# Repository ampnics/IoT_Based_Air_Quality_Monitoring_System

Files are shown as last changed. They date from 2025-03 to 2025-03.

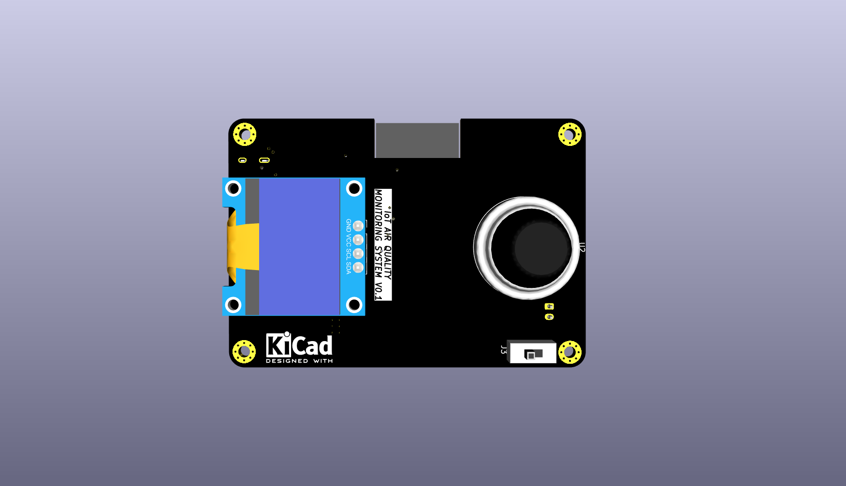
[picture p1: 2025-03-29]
Air_Quality_Monitor/Docs/Top_img.png

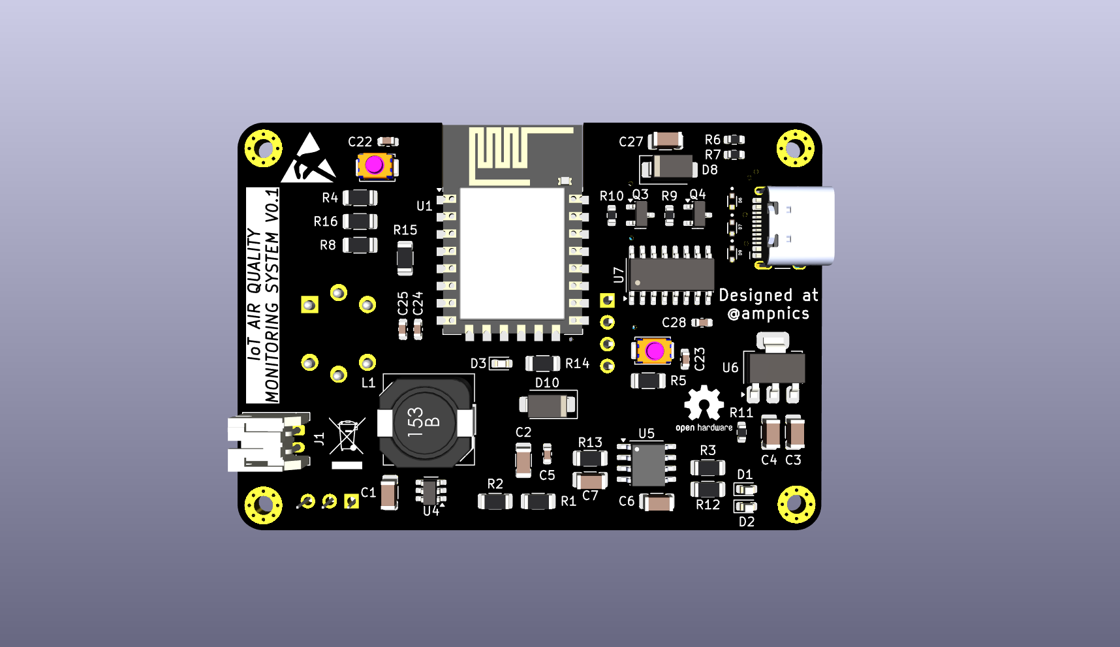
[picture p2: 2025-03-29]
Air_Quality_Monitor/Docs/Bottom_img.png

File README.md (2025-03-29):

# IoT_Based_Air_Quality_Monitoring_System
This project implements a real-time air quality monitoring system using IoT technology. It measures key environmental parameter like CO2 using sensors, then transmits data to a cloud platform via Wi-Fi.
A real-time air quality monitoring system that measures pollutants (CO2, NH3, NOx) and environmental parameters using IoT technology.

📋 Features
Real-time air quality monitoring using MQ135 gas sensor

OLED display for local readings

WiFi connectivity (ESP8266) for cloud data logging

Battery powered with TP4056 charging module

Compact design with CH340C USB-to-Serial interface

🛠 Hardware Components
ESP8266 - WiFi microcontroller

CH340C - USB-to-Serial converter

MT3608 - DC-DC boost converter (for 3.7V to 5V)

MQ135 - Air quality sensor (detects CO2, NH3, NOx)

AMS1117 - 3.3V voltage regulator

TP4056 - Lithium battery charging module

3.7V Li-ion Battery - Power source

0.96" OLED Display - I2C interface for local monitoring

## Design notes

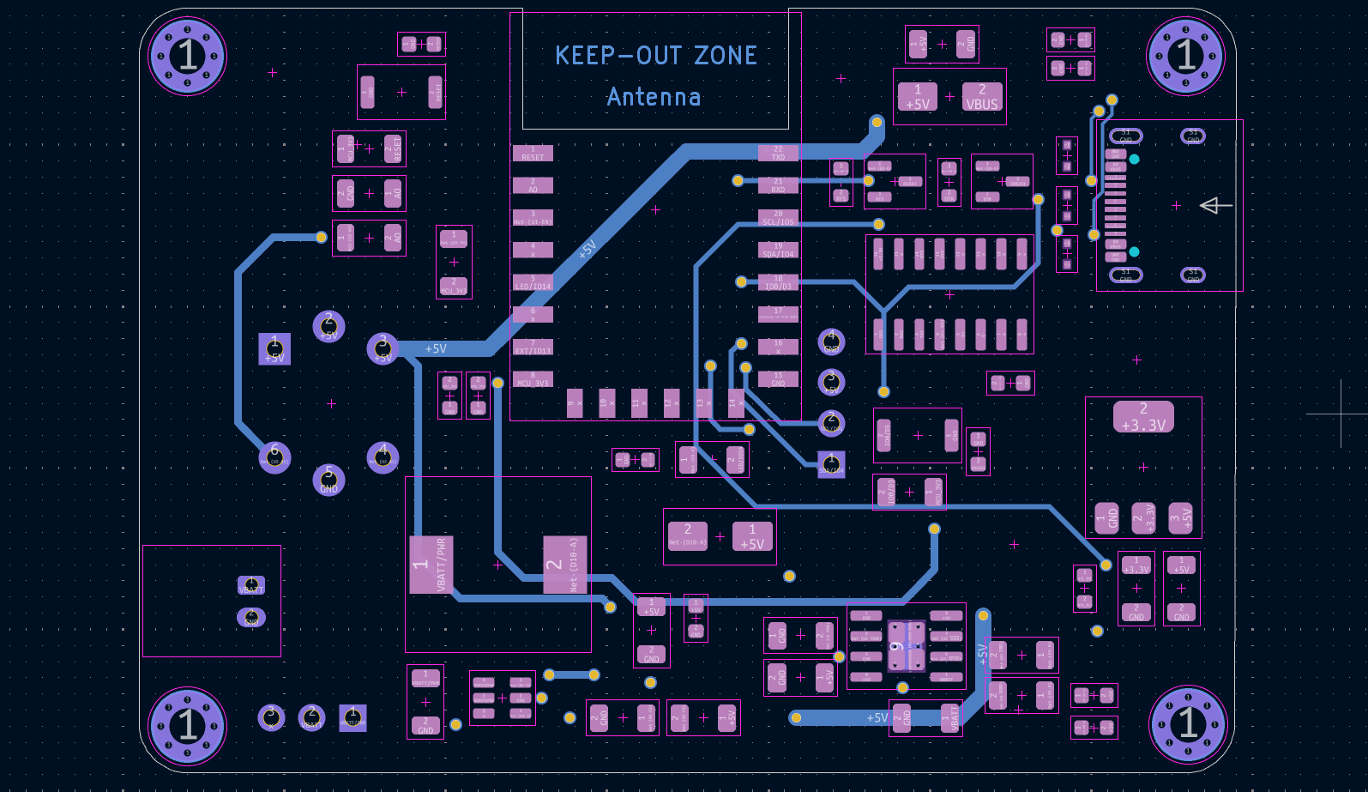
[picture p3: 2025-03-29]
Air_Quality_Monitor/Docs/B_Cu_Layout.png

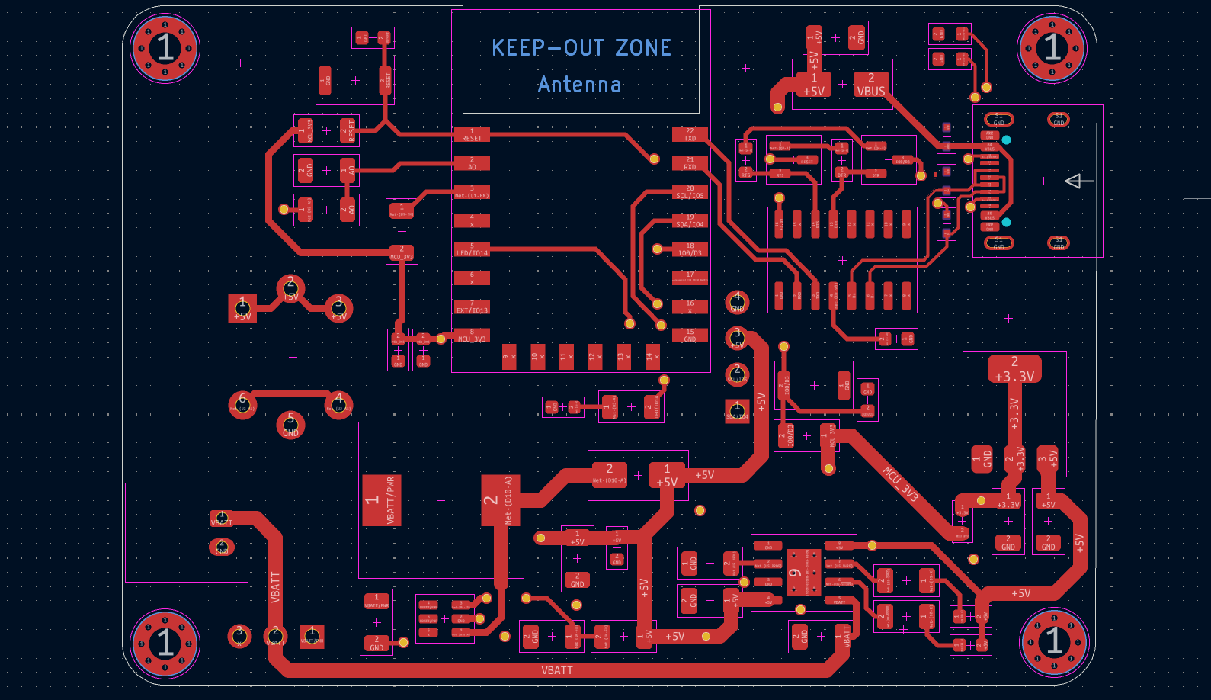
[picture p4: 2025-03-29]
Air_Quality_Monitor/Docs/F_Cu_Layout.png

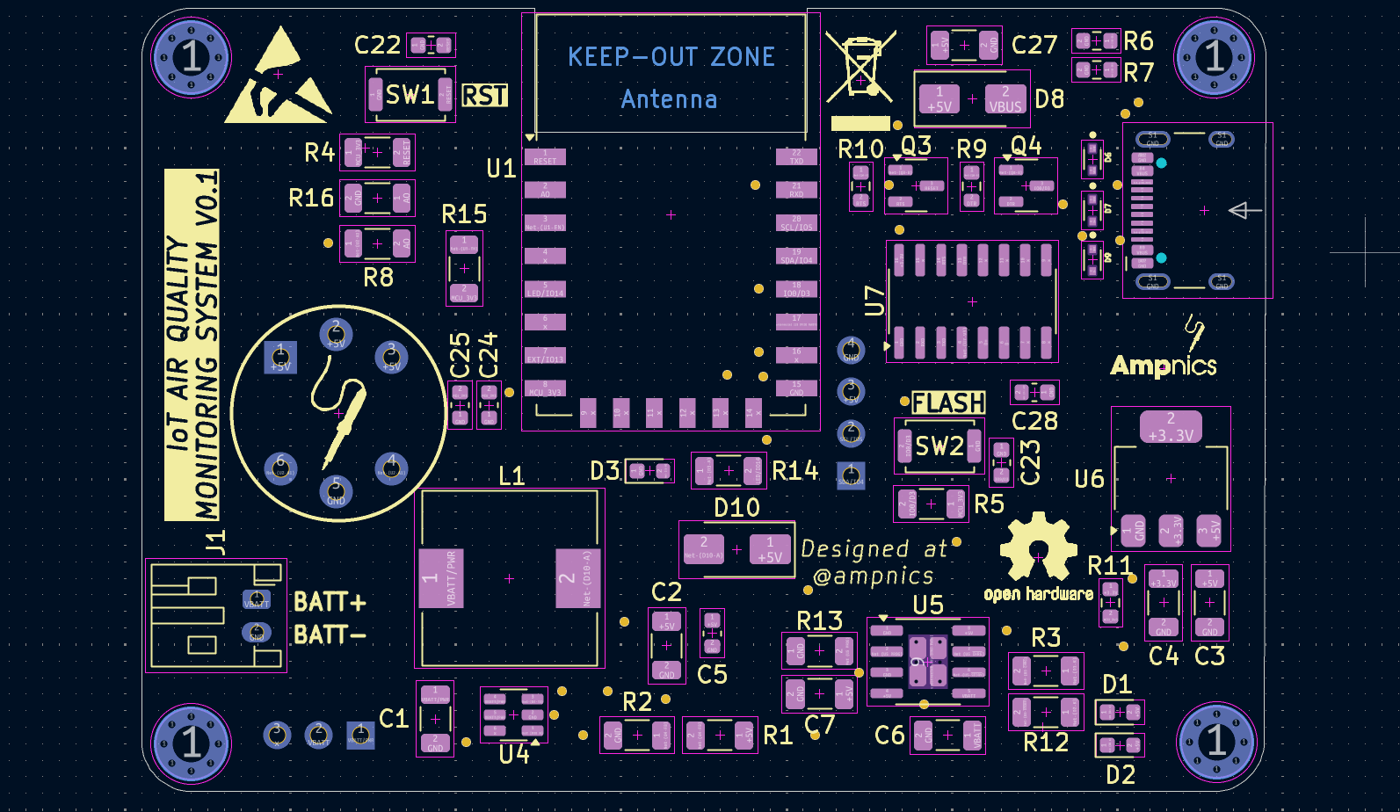
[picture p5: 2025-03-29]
Air_Quality_Monitor/Docs/F_Silkscreen.png

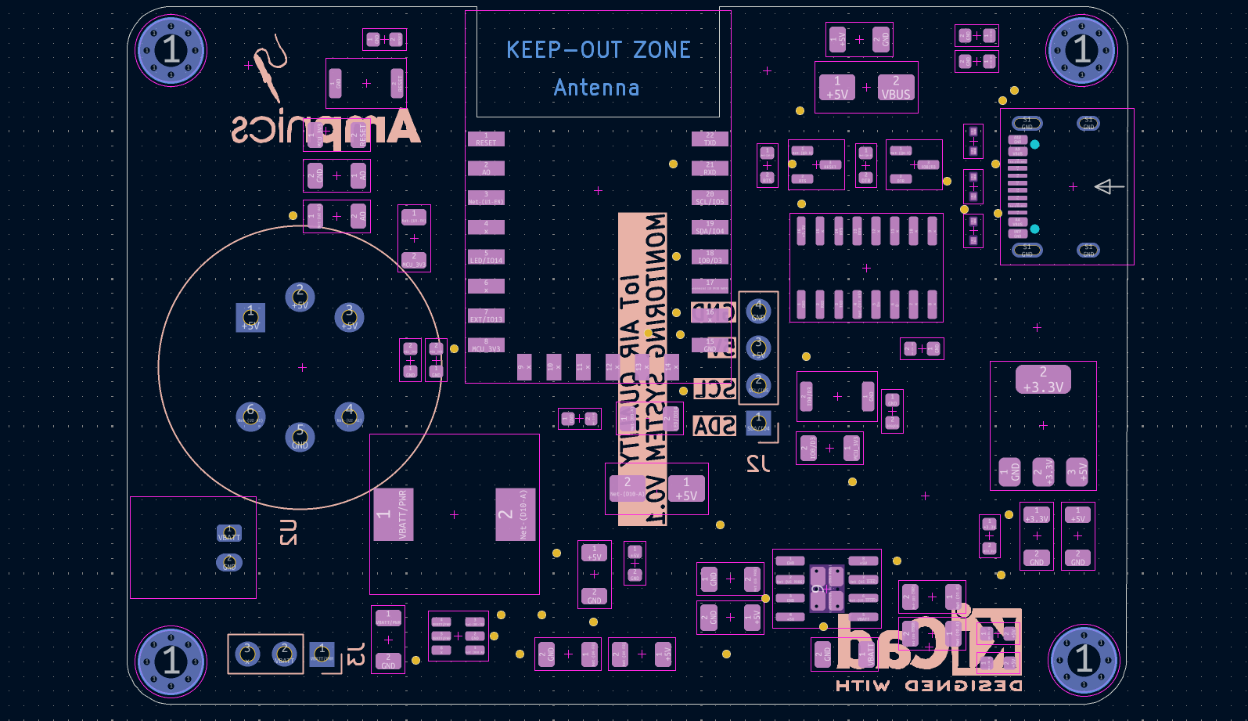
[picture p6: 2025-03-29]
Air_Quality_Monitor/Docs/B_Silkscreen.png

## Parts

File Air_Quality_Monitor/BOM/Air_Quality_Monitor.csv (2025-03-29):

Reference | Qty | Value | DNP | Exclude from BOM | Exclude from Board | Footprint | Datasheet
C1,C2 | 2 | 22uF |  |  |  | Capacitor_SMD:C_1206_3216Metric | ~
C3,C4,C6,C7 | 4 | 10uF |  |  |  | Capacitor_SMD:C_1206_3216Metric | ~
C5 | 1 | 0.1uF |  |  |  | Capacitor_SMD:C_0603_1608Metric | ~
C22,C23,C24,C25 | 4 | 0.1uf |  |  |  | Capacitor_SMD:C_0603_1608Metric | ~
C27 | 1 | 10uF/25V |  |  |  | Capacitor_SMD:C_1206_3216Metric | ~
C28 | 1 | 10nf |  |  |  | Capacitor_SMD:C_0603_1608Metric | ~
D1 | 1 | GREEN |  |  |  | LED_SMD:LED_0603_1608Metric | ~
D2,D3 | 2 | RED |  |  |  | LED_SMD:LED_0603_1608Metric | ~
D6,D7,D9 | 3 | LESD5D5.0CT1G |  |  |  | LESD5D5.0CT1G:TVS_LESD5D5.0CT1G
D8,D10 | 2 | SS34 |  |  |  | Diode_SMD:D_SMA | https://www.vishay.com/docs/88751/ss32.pdf
J1 | 1 | Conn_01x02_Pin |  |  |  | Connector_JST:JST_PH_S2B-PH-K_1x02_P2.00mm_Horizontal | ~
J2 | 1 | Conn_01x04_Pin |  |  |  | Connector_PinSocket_2.54mm:PinSocket_1x04_P2.54mm_Vertical | ~
J3 | 1 | Conn_01x03_Pin |  |  |  | Connector_PinHeader_2.54mm:PinHeader_1x03_P2.54mm_Vertical | ~
J23 | 1 | USB_C_Receptacle_USB2.0_16P |  |  |  | Connector_USB:USB_C_Receptacle_HCTL_HC-TYPE-C-16P-01A | https://www.usb.org/sites/default/files/documents/usb_type-c.zip
L1 | 1 | L |  |  |  | Inductor_SMD:L_10.4x10.4_H4.8 | ~
Q3,Q4 | 2 | SS8050 |  |  |  | Package_TO_SOT_SMD:SOT-23 | http://www.secosgmbh.com/datasheet/products/SSMPTransistor/SOT-23/SS8050.pdf
R1,R2 | 2 | R |  |  |  | Resistor_SMD:R_1206_3216Metric | ~
R3,R12,R16 | 3 | 1K |  |  |  | Resistor_SMD:R_1206_3216Metric | ~
R4,R5 | 2 | 10K |  |  |  | Resistor_SMD:R_1206_3216Metric | ~
R6,R7 | 2 | 5.1K |  |  |  | Resistor_SMD:R_0603_1608Metric | ~
R8 | 1 | 4.7K |  |  |  | Resistor_SMD:R_1206_3216Metric | ~
R9,R10 | 2 | 10k |  |  |  | Resistor_SMD:R_0603_1608Metric | ~
R11 | 1 | 0E |  |  |  | Resistor_SMD:R_0603_1608Metric | ~
R13 | 1 | 1K2 |  |  |  | Resistor_SMD:R_1206_3216Metric | ~
R14 | 1 | 220E |  |  |  | Resistor_SMD:R_1206_3216Metric | ~
R15 | 1 | 10k |  |  |  | Resistor_SMD:R_1206_3216Metric | ~
SW1,SW2 | 2 | SW_Push |  |  |  | Button_Switch_SMD:SW_Push_SPST_NO_Alps_SKRK | ~
U1 | 1 | ESP-12E |  |  |  | RF_Module:ESP-12E | http://wiki.ai-thinker.com/_media/esp8266/esp8266_series_modules_user_manual_v1.1.pdf
U2 | 1 | MQ-135 |  |  |  | Sensor:MQ-6 | https://www.winsen-sensor.com/d/files/semiconductor/mq-6.pdf
U4 | 1 | MT3608 |  |  |  | Package_TO_SOT_SMD:SOT-23-6 | https://www.olimex.com/Products/Breadboarding/BB-PWR-3608/resources/MT3608.pdf
U5 | 1 | TP4056-42-ESOP8 |  |  |  | Package_SO:SOIC-8-1EP_3.9x4.9mm_P1.27mm_EP2.41x3.3mm_ThermalVias | https://www.lcsc.com/datasheet/lcsc_datasheet_2410121619_TOPPOWER-Nanjing-Extension-Microelectronics-TP4056-42-ESOP8_C16581.pdf
U6 | 1 | AMS1117-3.3 |  |  |  | Package_TO_SOT_SMD:SOT-223-3_TabPin2 | http://www.advanced-monolithic.com/pdf/ds1117.pdf
U7 | 1 | CH340C |  |  |  | Package_SO:SOIC-16_3.9x9.9mm_P1.27mm | https://datasheet.lcsc.com/szlcsc/Jiangsu-Qin-Heng-CH340C_C84681.pdf

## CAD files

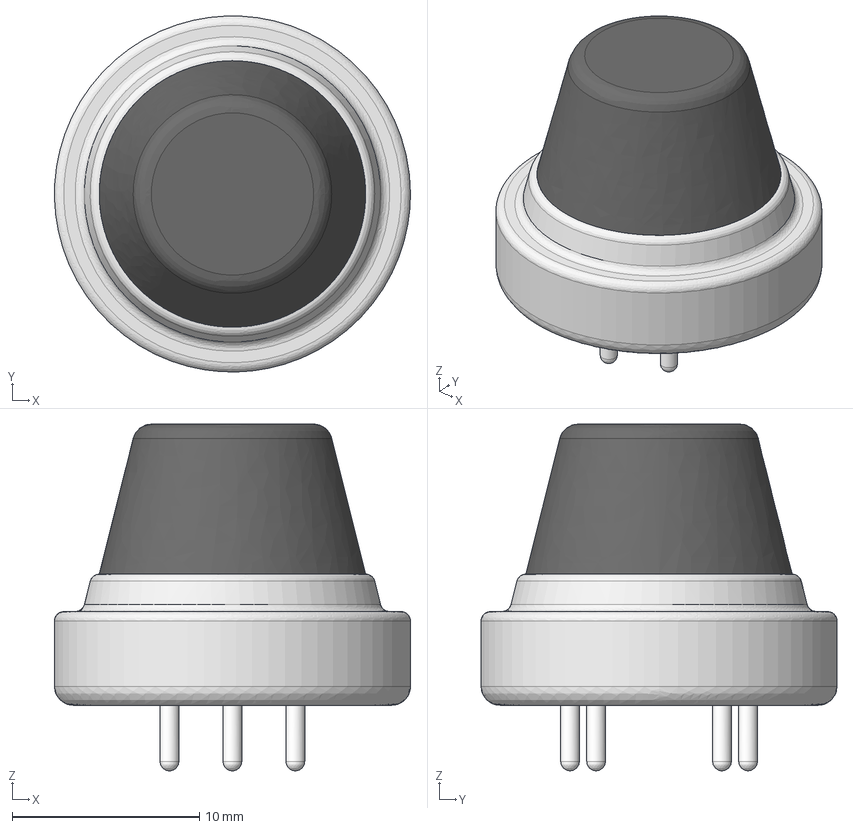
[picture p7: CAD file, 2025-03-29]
Air_Quality_Monitor/External 3d model/mq-8-gas-sensor-1.snapshot.1/MQ-8 gas sensor.stp
19.0 x 19.0 x 18.5 mm

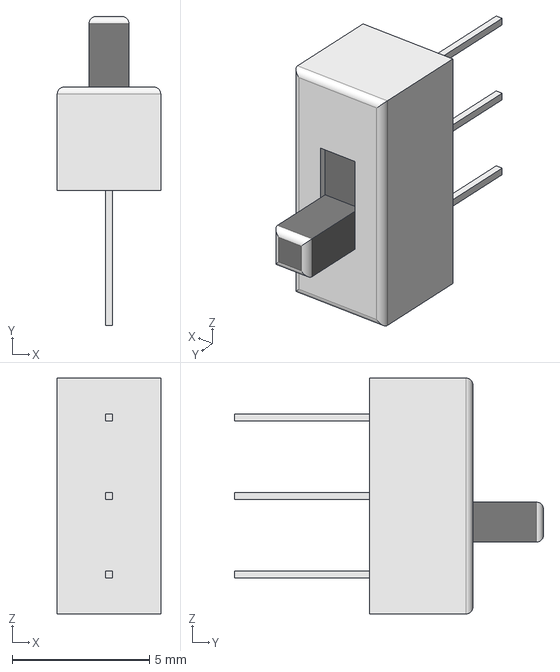
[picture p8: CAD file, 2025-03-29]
Air_Quality_Monitor/External 3d model/Vertical slide switch SS-12D00G3 High Knob 3mm SPDT v2.step
3.77 x 11.2 x 8.59 mm

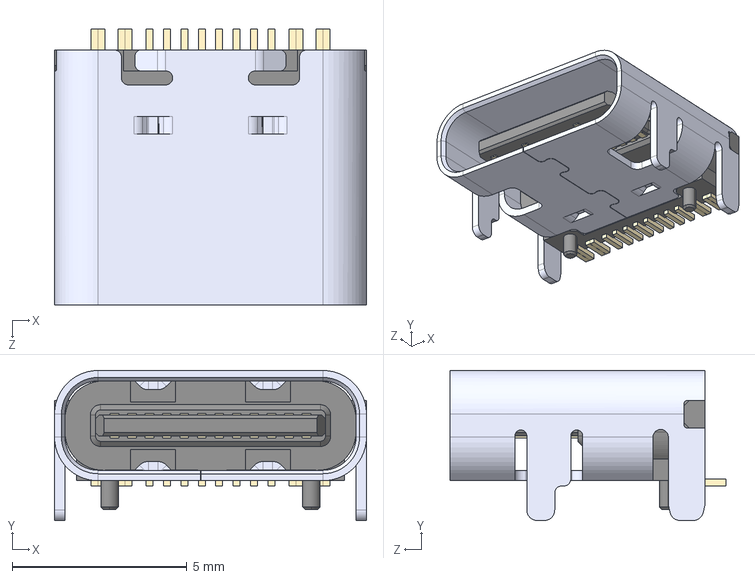
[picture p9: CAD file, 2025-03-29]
Air_Quality_Monitor/External 3d model/TYPE-C-31-M-12--3DModel-STEP-56544.STEP
8.94 x 4.30 x 7.90 mm

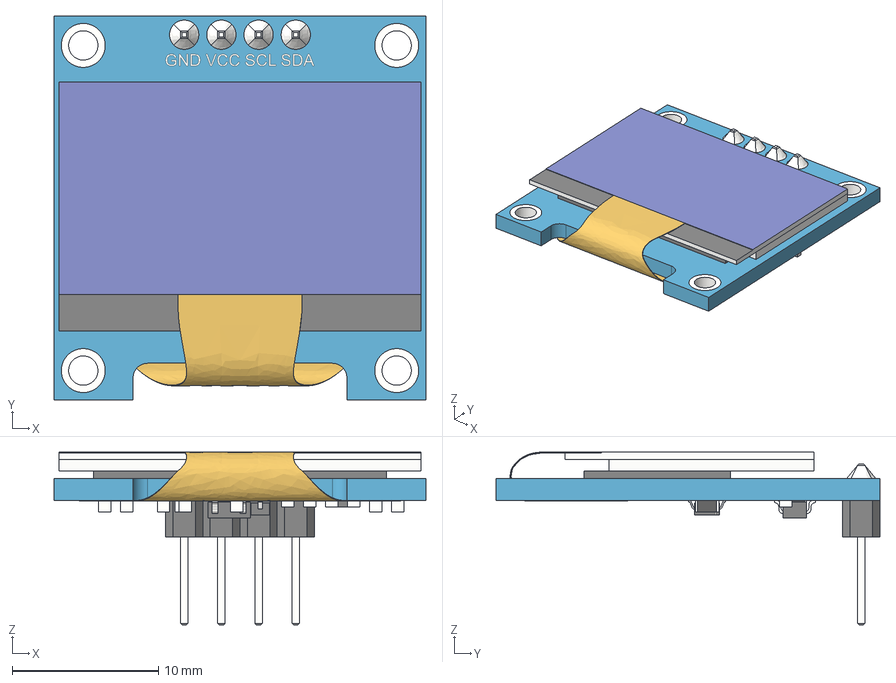
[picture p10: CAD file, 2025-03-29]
Air_Quality_Monitor/External 3d model/SSD1306_OLED_Display(128x64).step
25.4 x 26.2 x 11.8 mm
board
screen
pin_header
soldering
smd_capacitor
smd_capacitor (1)
914_smd_resistor
472_smd_resistor x 3
t4_smd_diode
smd_capacitor (2)
smd_capacitor (3)
smd_capacitor (4)
smd_capacitor (5)
smd_capacitor (6)
472_smd_resistor (1)
SOT-23_XC6206 v3
smd_capacitor (7)
flat_cable

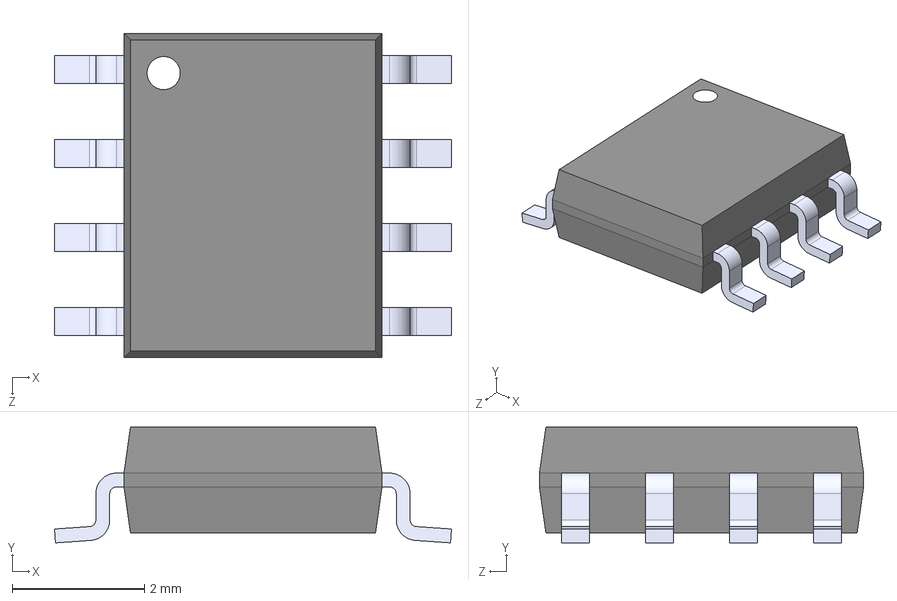
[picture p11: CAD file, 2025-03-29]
Air_Quality_Monitor/External 3d model/TP4056--3DModel-STEP-56544.STEP
6.00 x 1.75 x 4.90 mm

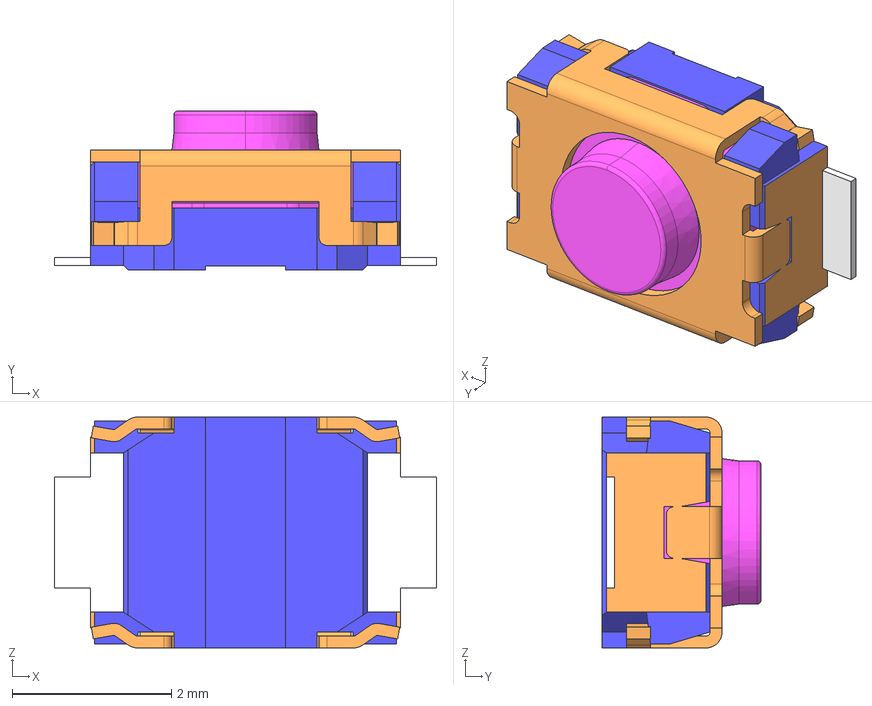
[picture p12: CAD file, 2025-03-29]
Air_Quality_Monitor/External 3d model/skrkaee010.stp
4.80 x 2.00 x 2.90 mm

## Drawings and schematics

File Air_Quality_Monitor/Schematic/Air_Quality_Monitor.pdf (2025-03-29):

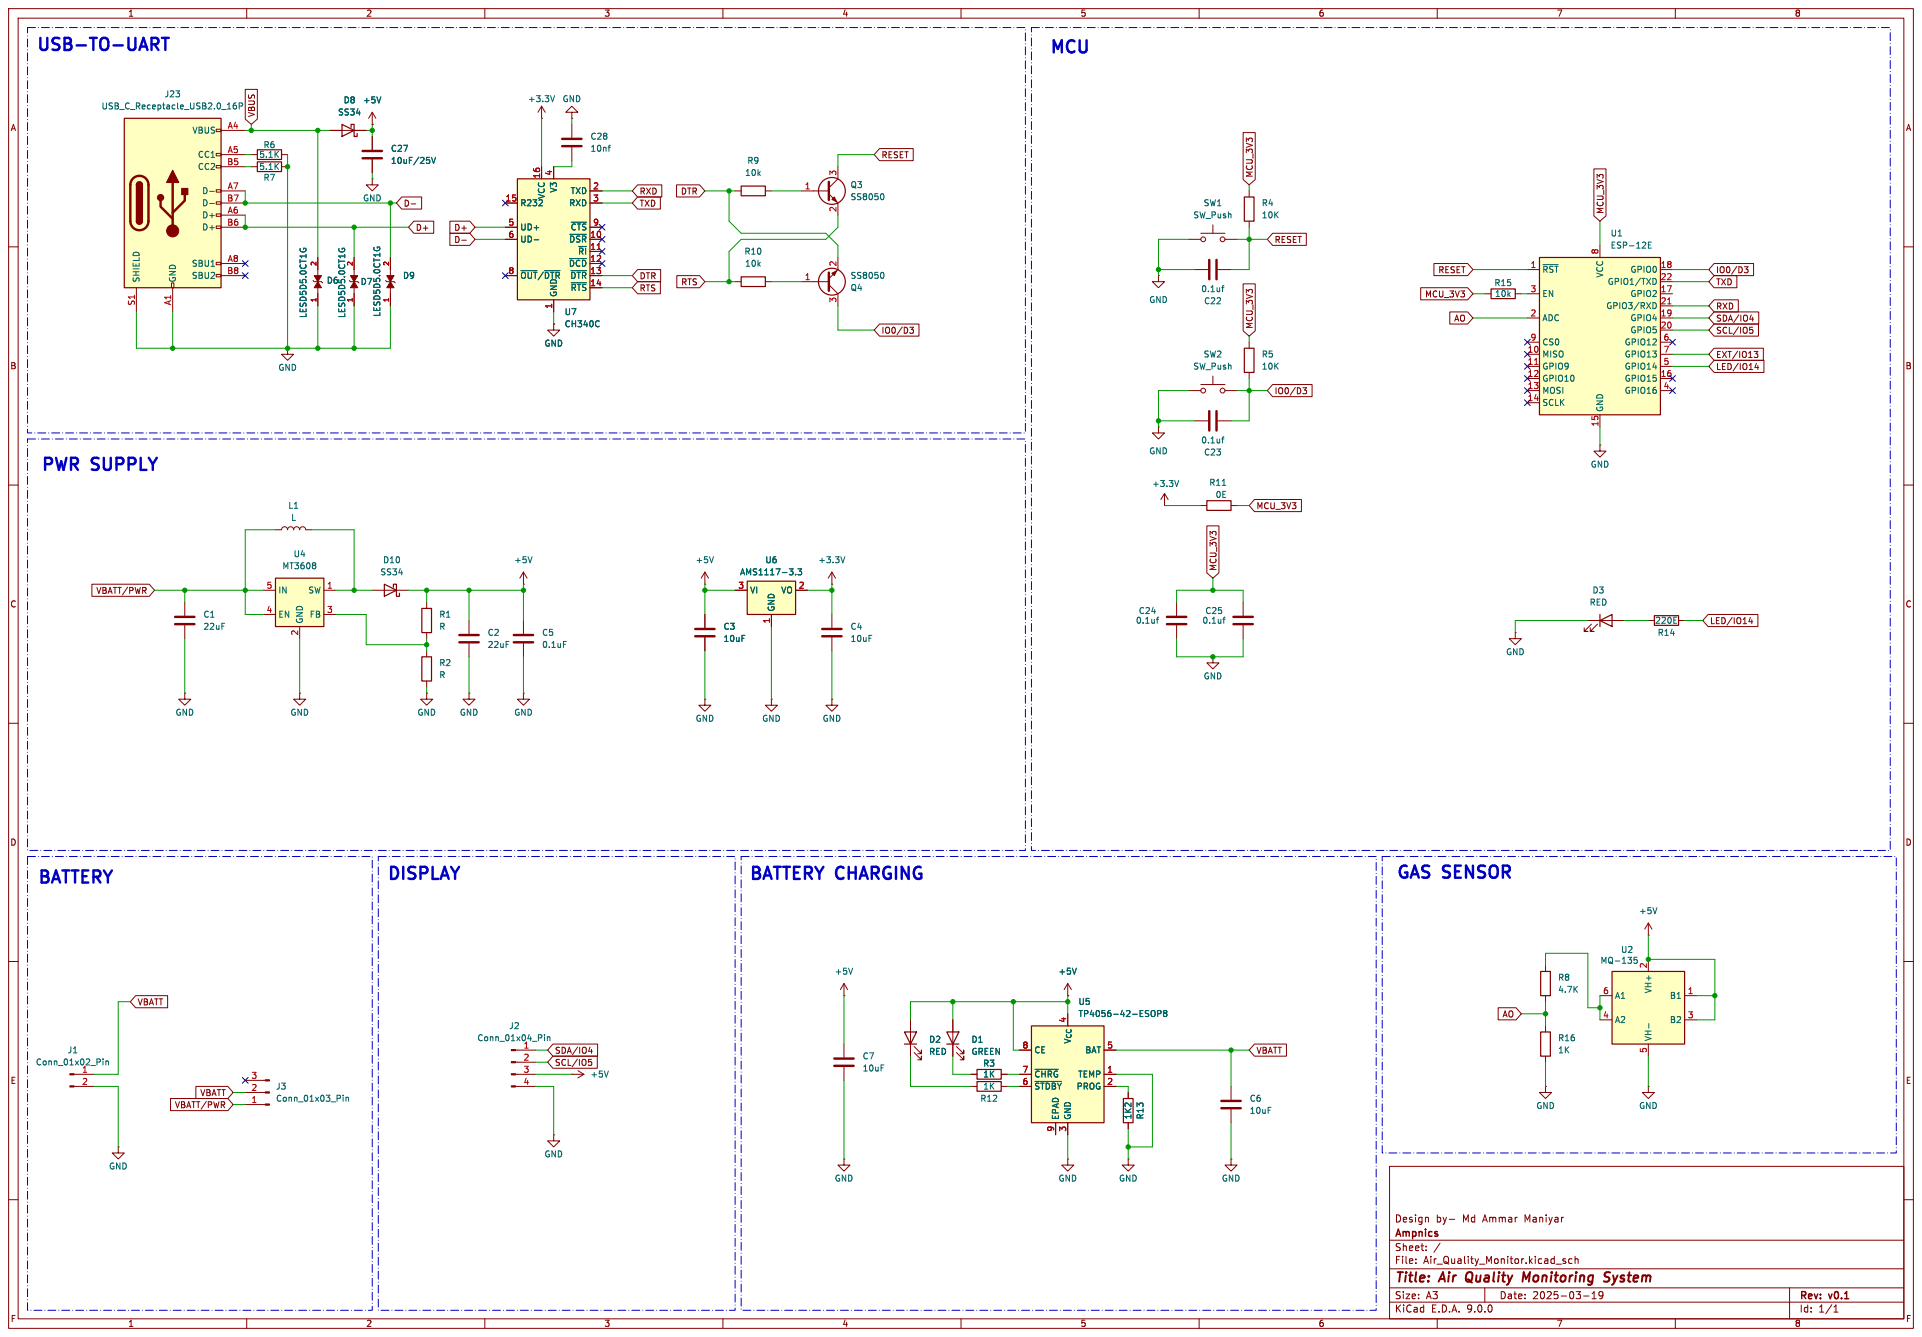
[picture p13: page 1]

1 TXD 2 RXD 3 ~{CTS}9 ~{DSR} 10 ~{RI} 11 ~{DCD} 12 ~{DTR} 13 ~{RTS} 14 GND

1 TXD 2 RXD 3 ~{CTS}9 ~{DSR} 10 ~{RI} 11 ~{DCD} 12 ~{DTR} 13 ~{RTS} 14 U7 CH340C

3 BAT 5 TEMP 1 PROG 2 1K2 R13 U6 AMS1117-3.3 VI 3 GND

3 BAT 5 TEMP 1 PROG 2 U5 TP4056-42-ESOP8 +5V GND GND GND GND

Id: 1/1 Title: Air Quality Monitoring System

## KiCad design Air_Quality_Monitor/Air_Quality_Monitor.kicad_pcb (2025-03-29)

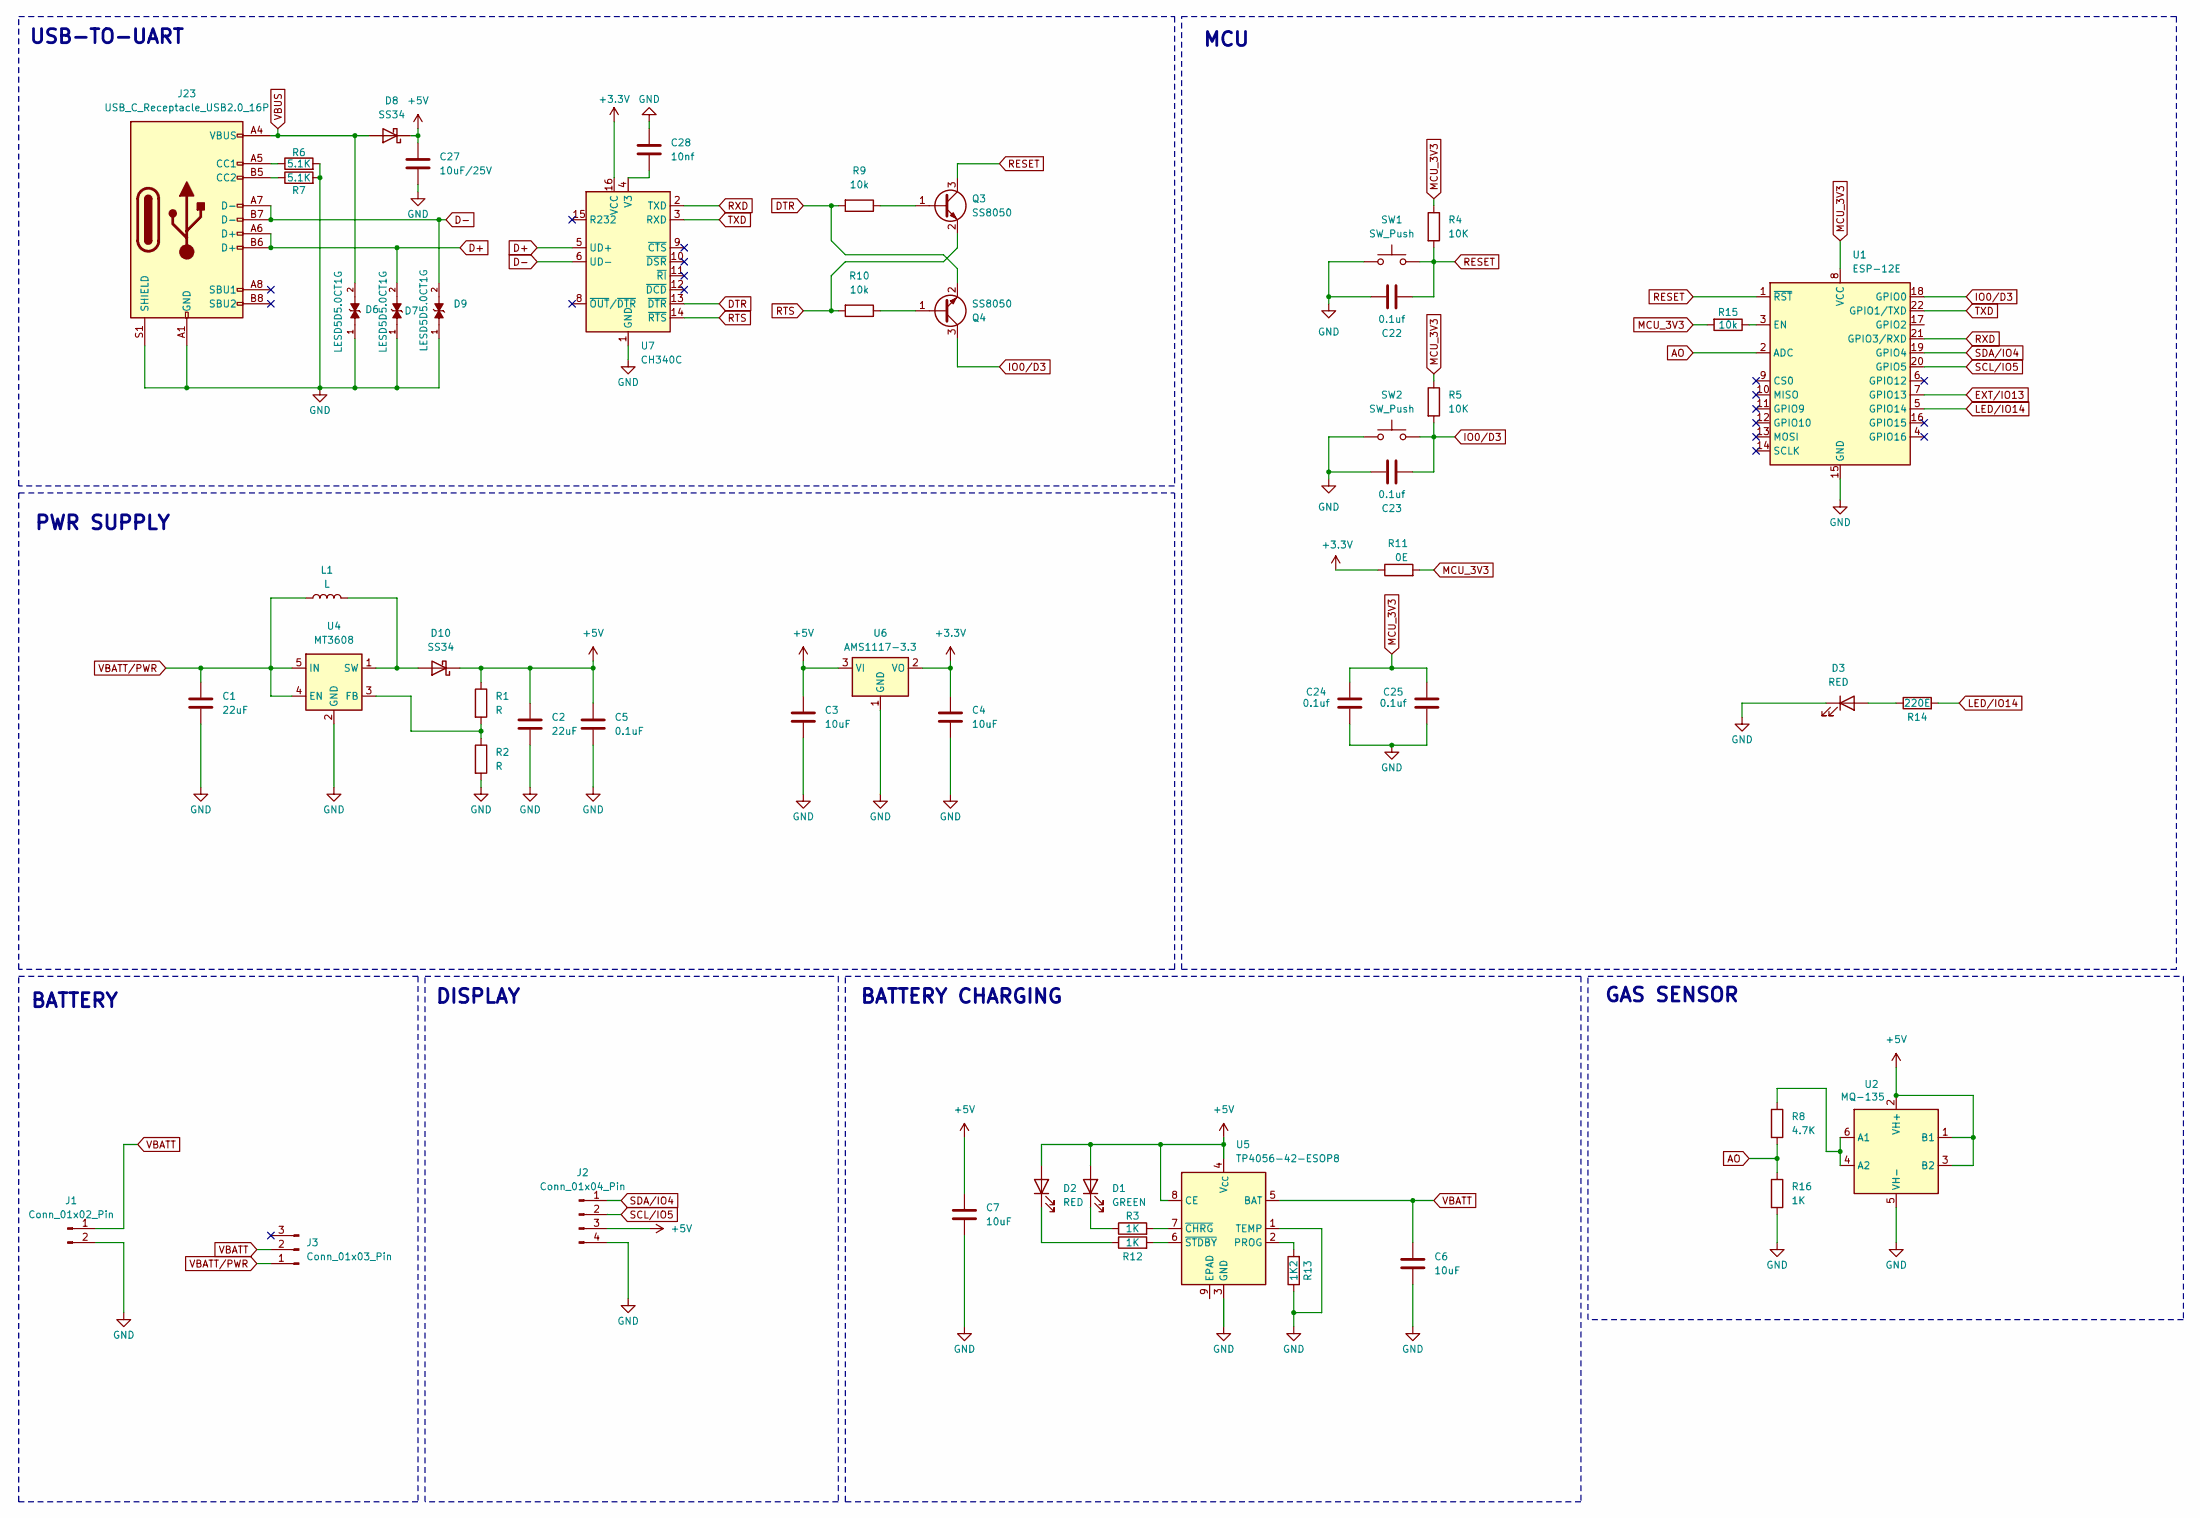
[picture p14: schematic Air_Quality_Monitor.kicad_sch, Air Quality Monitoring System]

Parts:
C1, C2: 22uF; C_1206_3216Metric
C3, C4, C6, C7: 10uF; C_1206_3216Metric
C5: 0.1uF; C_0603_1608Metric
C22, C23, C24, C25: 0.1uf; C_0603_1608Metric
C27: 10uF/25V; C_1206_3216Metric
C28: 10nf; C_0603_1608Metric
D1: GREEN; LED_0603_1608Metric
D2, D3: RED; LED_0603_1608Metric
D6, D7, D9: LESD5D5.0CT1G; TVS_LESD5D5.0CT1G; PARTREV O
D8, D10: SS34; D_SMA
J1: Conn_01x02_Pin; JST_PH_S2B-PH-K_1x02_P2.00mm_Horizontal
J2: Conn_01x04_Pin; PinSocket_1x04_P2.54mm_Vertical
J3: Conn_01x03_Pin; PinHeader_1x03_P2.54mm_Vertical
J23: USB_C_Receptacle_USB2.0_16P; USB_C_Receptacle_HCTL_HC-TYPE-C-16P-01A
L1: L; L_10.4x10.4_H4.8
Q3, Q4: SS8050; SOT-23
R1, R2: R; R_1206_3216Metric
R3, R12, R16: 1K; R_1206_3216Metric
R4, R5: 10K; R_1206_3216Metric
R6, R7: 5.1K; R_0603_1608Metric
R8: 4.7K; R_1206_3216Metric
R9, R10: 10k; R_0603_1608Metric
R11: 0E; R_0603_1608Metric
R13: 1K2; R_1206_3216Metric
R14: 220E; R_1206_3216Metric
R15: 10k; R_1206_3216Metric
SW1, SW2: SW_Push; SW_Push_SPST_NO_Alps_SKRK
U1: ESP-12E
U2: MQ-135; MQ-6
U4: MT3608; SOT-23-6
U5: TP4056-42-ESOP8; SOIC-8-1EP_3.9x4.9mm_P1.27mm_EP2.41x3.3mm_ThermalVias
U6: AMS1117-3.3; SOT-223-3_TabPin2
U7: CH340C; SOIC-16_3.9x9.9mm_P1.27mm

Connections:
+3.3V: C4.1, R11.1, U6.2 (VO), U7.16 (VCC)
+5V: C2.1, C3.1, C5.1, C7.1, C27.1, D1.2 (A), D2.2 (A), D8.1 (K), D10.1 (K), J2.3, R1.1, U2.1 (B1), U2.2 (VH+), U2.3 (B2), U5.4 (V_{CC}), U5.8 (CE), U6.3 (VI)
AO: R8.2, R16.1, U1.2 (ADC)
D+: D7.2, J23.A6 (D+), J23.B6 (D+), U7.5 (UD+)
D-: D9.2, J23.A7 (D-), J23.B7 (D-), U7.6 (UD-)
DTR: Q4.2 (E), R9.2, U7.13 (~DTR)
EXT/IO13: U1.7 (GPIO13)
GND: C1.2, C2.2, C3.2, C4.2, C5.2, C6.2, C7.2, C22.1, C23.1, C24.1, C25.1, C27.2, C28.1, D3.1 (K), D6.1, D7.1, D9.1, J1.2, J2.4, J23.A1 (GND), J23.A12 (GND), J23.B1 (GND), J23.B12 (GND), J23.S1 (SHIELD), R2.2, R6.2, R7.2, R13.1, R16.2, SW1.1, SW2.1, U1.15 (GND), U2.5 (VH-), U4.2 (GND), U5.1 (TEMP), U5.3 (GND), U6.1 (GND), U7.1 (GND)
IO0/D3: C23.2, Q4.3 (C), R5.2, SW2.2, U1.18 (GPIO0)
LED/IO14: R14.2, U1.5 (GPIO14)
MCU_3V3: C24.2, C25.2, R4.1, R5.1, R11.2, R15.2, U1.8 (VCC)
unnamed: D1.1 (K), R3.1
unnamed: D2.1 (K), R12.1
unnamed: D3.2 (A), R14.1
unnamed: D10.2 (A), L1.2, U4.1 (SW)
unnamed: J23.A5 (CC1), R6.1
unnamed: J23.B5 (CC2), R7.1
unnamed: Q3.1 (B), R9.1
unnamed: Q4.1 (B), R10.1
unnamed: R15.1, U1.3 (EN)
unnamed: R8.1, U2.4 (A2), U2.6 (A1)
unnamed: R1.2, R2.1, U4.3 (FB)
unnamed: R13.2, U5.2 (PROG)
unnamed: R3.2, U5.7 (~CHRG)
unnamed: R12.2, U5.6 (~STDBY)
unnamed: C28.2, U7.4 (V3)
RESET: C22.2, Q3.3 (C), R4.2, SW1.2, U1.1 (~RST)
RTS: Q3.2 (E), R10.2, U7.14 (~RTS)
RXD: U1.21 (GPIO3/RXD), U7.2 (TXD)
SCL/IO5: J2.2, U1.20 (GPIO5)
SDA/IO4: J2.1, U1.19 (GPIO4)
TXD: U1.22 (GPIO1/TXD), U7.3 (RXD)
VBATT: C6.1, J1.1, J3.2, U5.5 (BAT)
VBATT/PWR: C1.1, J3.1, L1.1, U4.4 (EN), U4.5 (IN)
VBUS: D6.2, D8.2 (A), J23.A4 (VBUS), J23.A9 (VBUS), J23.B4 (VBUS), J23.B9 (VBUS)

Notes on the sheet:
PWR SUPPLY
USB-TO-UART
DISPLAY
GAS SENSOR
BATTERY CHARGING
MCU
BATTERY

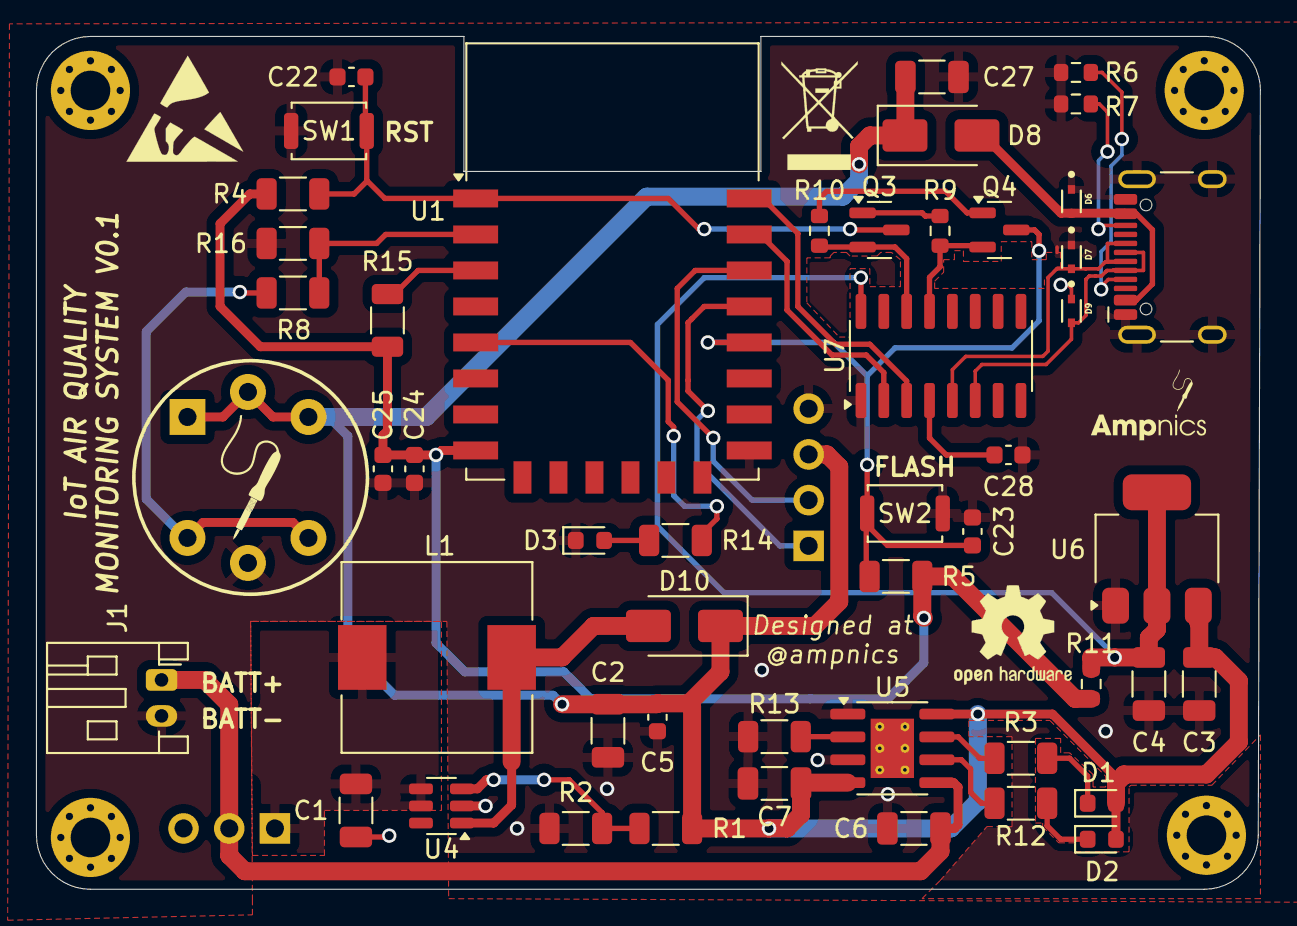
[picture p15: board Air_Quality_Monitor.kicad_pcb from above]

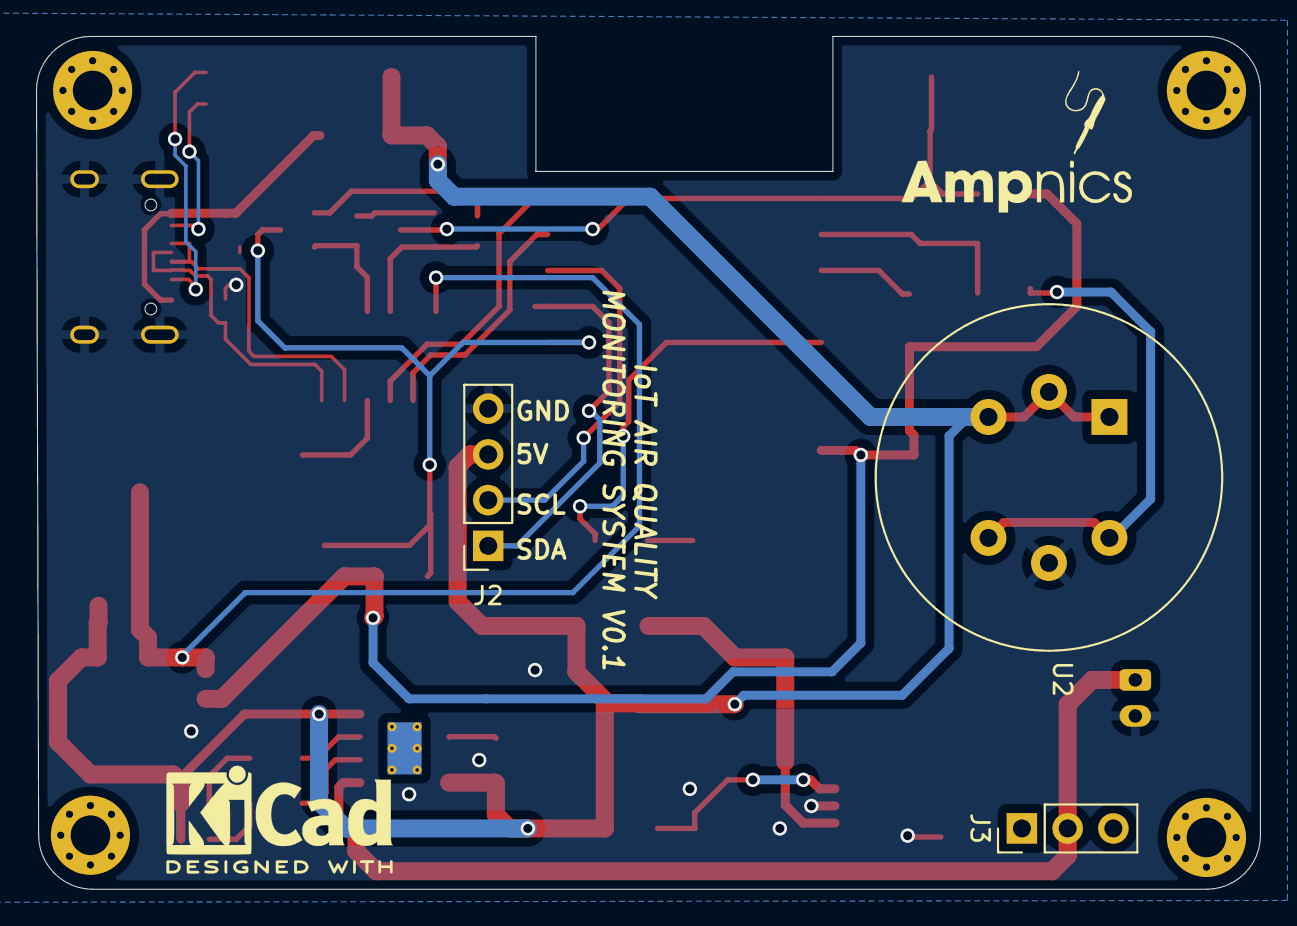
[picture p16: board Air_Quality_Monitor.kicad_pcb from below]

Board: 2 copper layers, 68.0 x 47.4 mm, 56 parts (3 on the bottom side), 34 nets.

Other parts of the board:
REFe: MountingHole_2.2mm_M2_Pad_Via
REFe#2, REFe#3, REFe#4: MountingHole_2.2mm_M2_Pad_Via
